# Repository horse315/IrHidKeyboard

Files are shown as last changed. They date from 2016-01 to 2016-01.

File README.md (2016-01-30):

# IrHidKeyboard
IR remote control for my Car PC. Emulates keyboard and mouse USB HID Combo device.

## Hardware

- Digispark USB board or other attiny85 controller
- Any 38kHz IR receiver
- 10 kOhm resistor

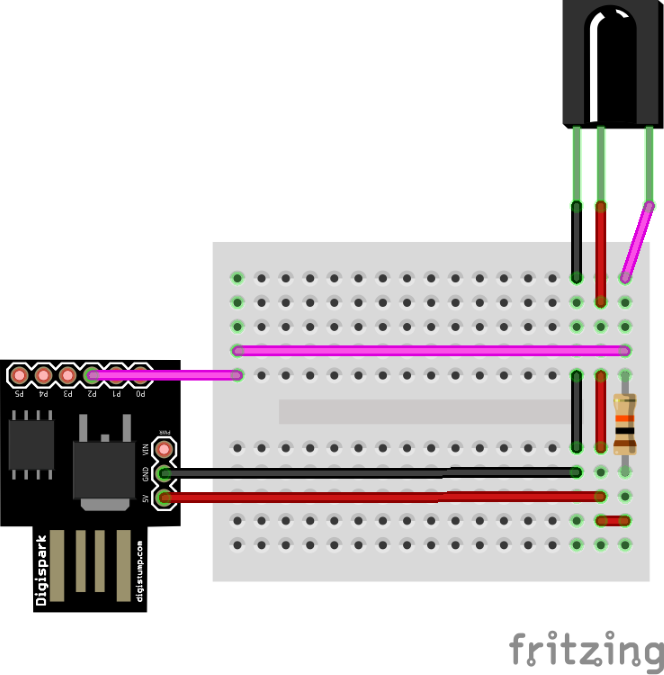
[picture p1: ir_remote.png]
prototype scheme


## Software

- Arduino IDE 1.6 with Digispark boards support
- Adafruit HID Combo libraries (also included in src/libraries): https://github.com/adafruit/Adafruit-Trinket-USB

## Description
Device emulates pressing keyboard media and other keys and key combinations. IR receiver data output is connected to PIN_2 (INT_0) of Digispark board. Also you can add hardware resistance key support. 

### Story
The idea was to make a small device compatible with all possible DIY Car PC systems (commonly Windows or Android/Linux). I tried Arduino HID Keyboard firmware on my Arduino UNO and Digikeyboard library on Digispark with standard IR Decode libraries, but media keys (play/pause, next, previous track) did not work in Windows for both. So I found these great Adafruit HID libraries that solve problem with media keys, but with them and IR libraries compilled sketch was too big for Digispark board. IR libraries provided with Digispark and Arduino have big overhead of different protocols implemetation, while most remotes in DIY kits from ebay use only NEC IR  protocol. So I wrote this slim implementation that uses about 4200 bytes! Also you can connect wheel media keys to controller - 1800 bytes left.

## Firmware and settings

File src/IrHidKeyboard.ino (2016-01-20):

#include "TrinketHidCombo.h"

// Led pin depends on board revision
#define LED_PIN 1

// IR receiver is connected to PIN_2 (INT_0)
#define IR_PIN 2
#define IR_INT 0

// IR command codes
#define PLAY  40
#define UP     88
#define DOWN   120
#define LEFT   104
#define RIGHT  24
#define POWER     72
#define BAND   232
#define SOURCE 8
#define VOL_UP  216
#define VOL_DWN 248

int pos = 0;
uint32_t data = 0;

uint8_t addressToRead = 0;
uint8_t commandToRead = 0;
bool timeToRead = false;

uint16_t timePrev = 0;

void setup()
{
  pinMode(LED_PIN, OUTPUT);

  pinMode(IR_PIN, INPUT);
  attachInterrupt(IR_INT, irRead, FALLING);

  TrinketHidCombo.begin();
}


void loop()
{
  if (timeToRead)
  {
    digitalWrite(LED_PIN, HIGH);

/*
    // Uncomment this code to with keyboard IR command codes
    char str[15];
    sprintf(str, "%d", commandToRead);
    TrinketHidCombo.println(str);
*/

    switch (commandToRead)
    {
      case VOL_UP:
        TrinketHidCombo.pressMultimediaKey(MMKEY_VOL_UP);
        break;
      case VOL_DWN:
        TrinketHidCombo.pressMultimediaKey(MMKEY_VOL_DOWN);
        break;
      case PLAY:
        TrinketHidCombo.pressMultimediaKey(MMKEY_PLAYPAUSE);
        break;
      case LEFT:
        TrinketHidCombo.pressMultimediaKey(MMKEY_SCAN_PREV_TRACK);
        break;
      case RIGHT:
        TrinketHidCombo.pressMultimediaKey(MMKEY_SCAN_NEXT_TRACK);
        break;
      case POWER:
        TrinketHidCombo.pressKey(0x0, KEYCODE_ESC);
        TrinketHidCombo.pressKey(0, 0);
        break;
      case SOURCE:
        TrinketHidCombo.pressKey(KEYCODE_MOD_LEFT_ALT, KEYCODE_ESC);
        TrinketHidCombo.pressKey(0, 0);
        break;
      case UP:
        TrinketHidCombo.pressKey(KEYCODE_MOD_LEFT_GUI, KEYCODE_A);
        TrinketHidCombo.pressKey(0, 0);
        break;
      case DOWN:
        TrinketHidCombo.pressKey(KEYCODE_MOD_LEFT_GUI, KEYCODE_D);
        TrinketHidCombo.pressKey(0, 0);
        break;
      case BAND:
        break;
      default:
        break;
    }

    digitalWrite(LED_PIN, LOW);

    timeToRead = false;
  }

  TrinketHidCombo.poll();
}

void irRead() {
  uint16_t time = micros();
  uint16_t dt = time - timePrev;

  timePrev = time;

  int dtState = deltaState(dt);

  if (dtState == 1) {
    clear();
  } else if (dtState == 2) {
    data |= (dt > 1500);

    if (pos < 31) {
      data <<= 1;
      pos++;
    } else {
      timeToRead = false;
      addressToRead = (uint8_t)((data >> 24) & 0xff);
      commandToRead = (uint8_t)((data >> 8) & 0xff);
      timeToRead = true;
    }
  }
}

int deltaState(uint16_t dt) {
  if (dt > 12000 && dt < 14000) {
    // begin
    return 1;
  } else if (dt > 1000 && dt < 2500) {
    // data
    return 2;
  } else {
    return 0;
  }
}

void clear() {
  pos = 0;
  data = 0;
  timeToRead = false;
}

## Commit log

2016-01-29 Added arduino prototype image
2016-01-30 Normal scheme
    [ir_keyboard.fzz]
